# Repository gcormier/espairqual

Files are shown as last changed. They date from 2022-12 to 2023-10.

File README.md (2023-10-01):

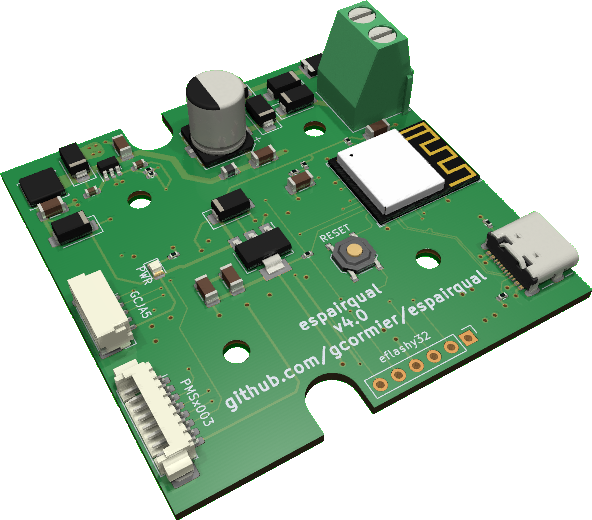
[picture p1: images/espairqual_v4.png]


# espairqual
espairqual is an ESP32 based [esphome](https://esphome.io/) interface for [PMSx003](https://esphome.io/components/sensor/pmsx003.html) and [Panasonic NA-GCJA5](https://na.industrial.panasonic.com/products/sensors/air-quality-gas-flow-sensors/lineup/laser-type-pm-sensor/series/123557/model/123559) particulate matter (PM) sensors.



It offers a plug and play solution to integrate air quality monitoring with home assistant. It provides 5V to the sensor and 3.3V to the internal electronics.

It can be powered by USC-C, or, by a wider range of input voltages on the screw terminals. It was designed for 24VAC, but will likely work with a slightly broader range
of both AC and DC input voltages. The absolute maximum voltage for the switching regulator is 40VDC, which means up to around 28VAC. The minimum DC is approximately 9VDC.

The PCB will fit inside a [Hammond 1593KBK](https://www.hammfg.com/part/1593KBK) case. You can either cut (CNC) or 3D-print the faceplates. I have superglue'd some magnets inside the case so it can stick to my ductwork, although this attenuates the WiFi signal *alot*.

## Programming
The USB-C port can be used to program. The first time, the reset button must be held. After this, all subsequent programming does not require access to the button.

There is also a header for the typical serial flashing with GPIO0(9) and EN exposed. It follows my [eflashy32](https://github.com/gcormier/eflashy32) pinout.

## Panasonic SN-GCJA5
I contributed native support for the SN-GCJA5 [to esphome](https://esphome.io/components/sensor/gcja5.html). While the PMS5003 is a good sensor, I did receive one dead-on-arrival from Aliexpress. The Panasonic sensor is cheaper, smaller, available from tier-1 distributors (eg. [Digikey](https://www.digikey.ca/en/products/detail/panasonic-electronic-components/SN-GCJA5/10443899)) and has a 5+ year life expectancy. It has internal compensation for the fan, photo diode and laser diode.

The connector is JST-GH (1.25mm) series.

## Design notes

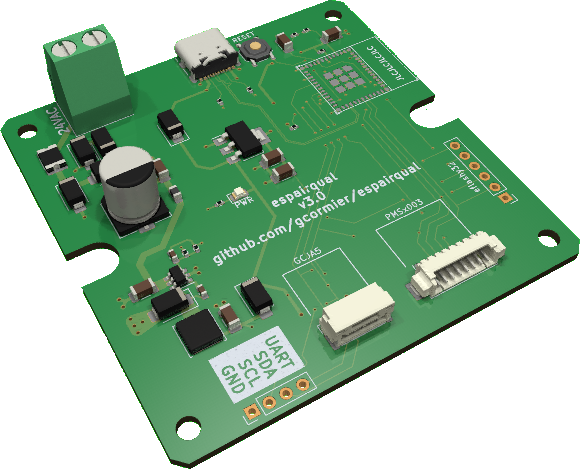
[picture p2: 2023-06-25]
images/espairqual_v3.png

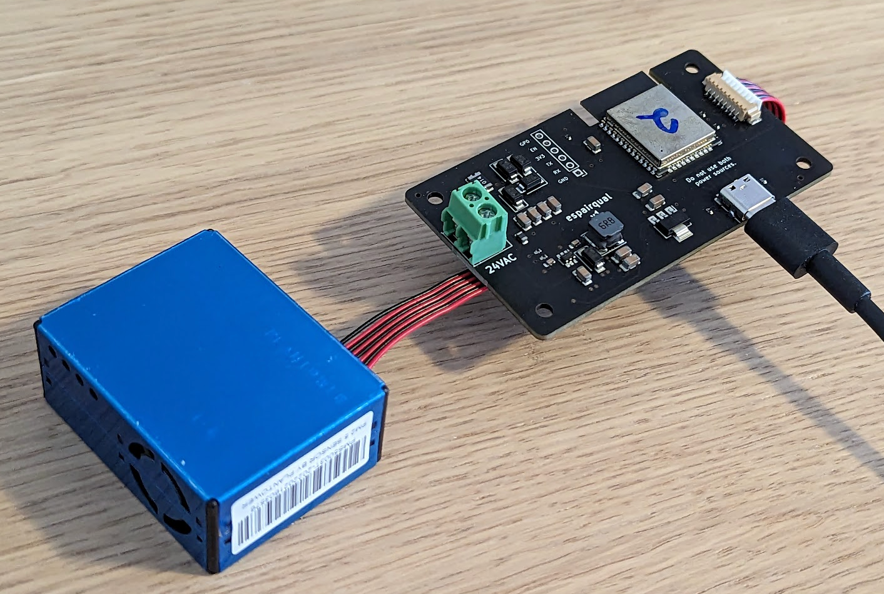
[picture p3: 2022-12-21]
images/espairqual.png

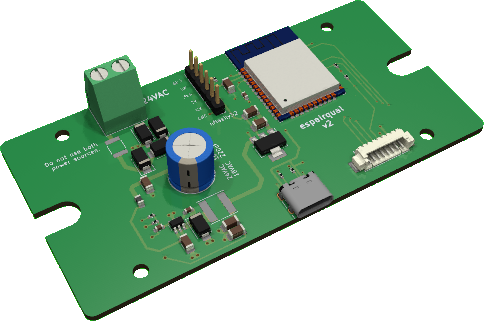
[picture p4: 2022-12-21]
images/espairqual-3D.png

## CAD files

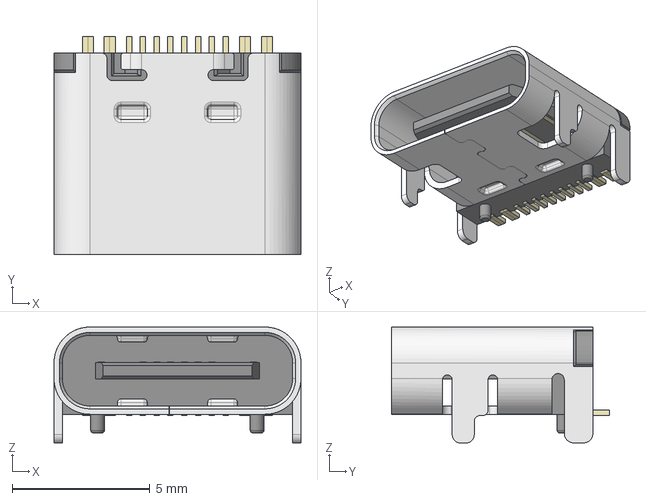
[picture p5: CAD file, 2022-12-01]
pcb/HRO_TYPE-C-31-M-12.step
8.95 x 7.90 x 4.20 mm

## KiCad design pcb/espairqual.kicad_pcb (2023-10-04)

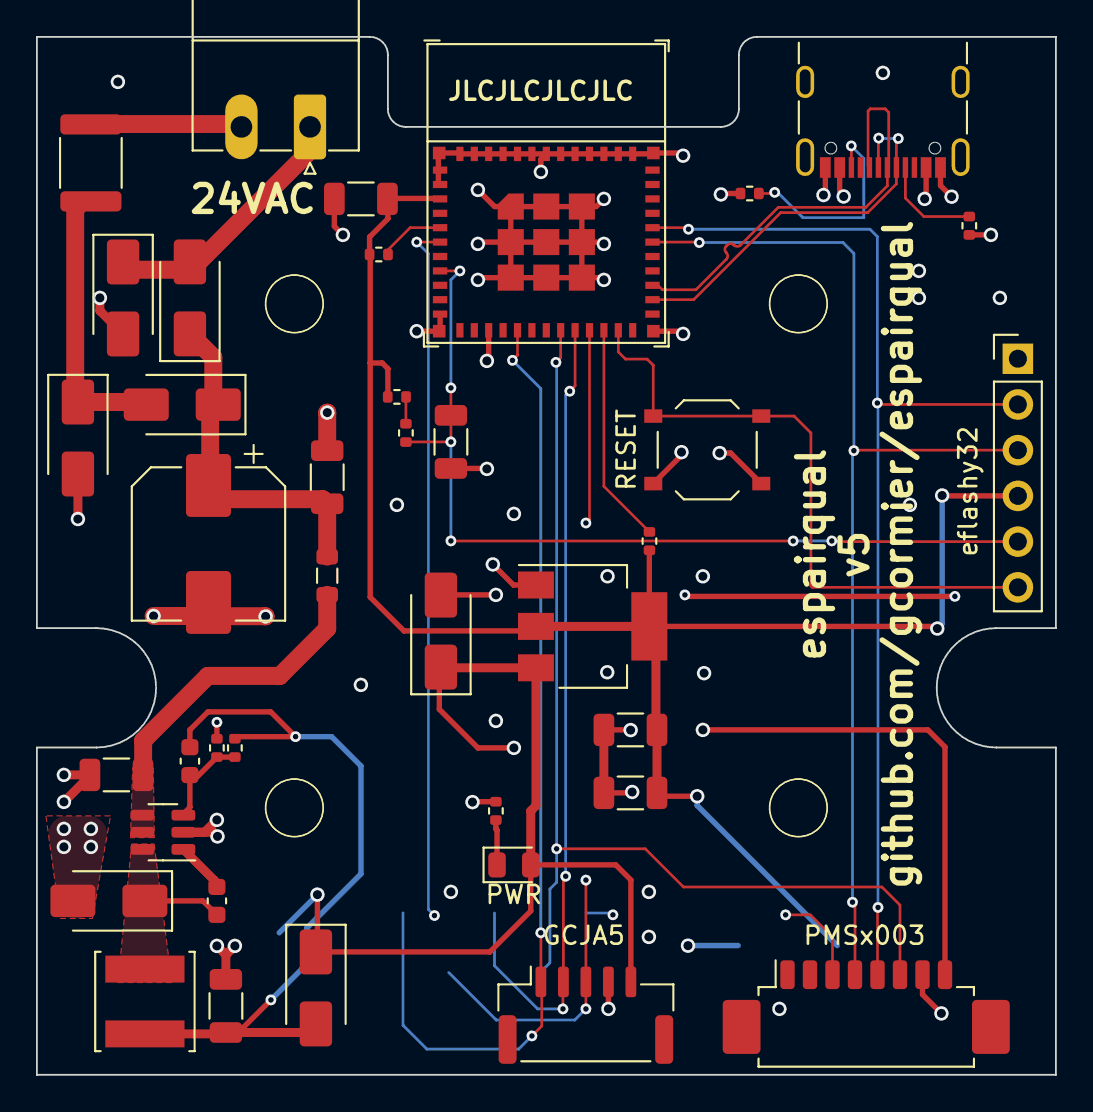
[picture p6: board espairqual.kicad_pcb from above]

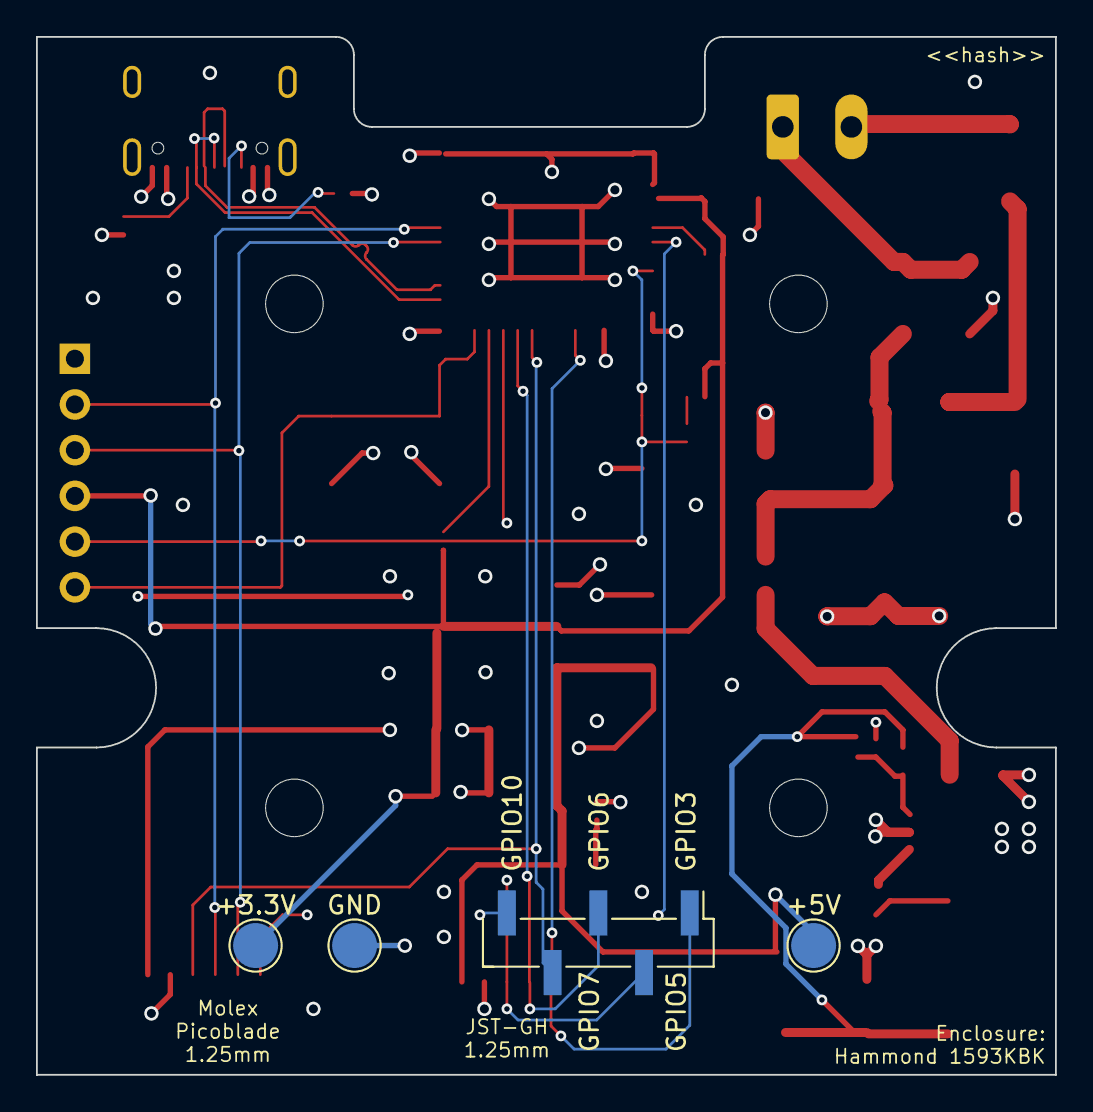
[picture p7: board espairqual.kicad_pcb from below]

Board: 4 copper layers, 56.6 x 57.7 mm, 47 parts (4 on the bottom side), 30 nets.

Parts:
C1, C6, C7, C8, C9, C11, C12: 10uF 50V; C_1206_3216Metric
C4: 0.1u 25v; C_0603_1608Metric
C5: 15nF; C_0603_1608Metric
C10: 100uF 50V; CP_Elec_8x10
D1, D2, D3, D4, D5, D6, D7: SS210; D_SMA
D8: PWR; LED_0805_2012Metric
F1: 140mA hold / 340mA trip mSMD014; Fuse_1812_4532Metric
FB1: 600@100MHz; L_0805_2012Metric
H1, H2, H3, H4: MountingHole; MountingHole_3.2mm_M3
J1: 24VAC; PhoenixContact_MC_1,5_2-G-3.81_1x02_P3.81mm_Horizontal
J2: PMSX003; Molex_PicoBlade_53261-0871_1x08-1MP_P1.25mm_Horizontal
J3: eflashy32; PinHeader_1x06_P2.54mm_Vertical
J4: USBC; USB_C_Receptacle_GCT_USB4105-xx-A_16P_TopMnt_Horizontal
J5: GCJA5; JST_GH_SM05B-GHS-TB_1x05-1MP_P1.25mm_Horizontal
J7: AUX; PinHeader_1x05_P2.54mm_Vertical_SMD_Pin1Left
L1: 6.8uH; L_Sunlord_SWPA5012S
R1, R3, R4, R5, R10, R11: 5k1; R_0402_1005Metric
R2, R6: 680; R_0402_1005Metric
R12: 3k9; R_0402_1005Metric
SW1: RESET; SW_Push_1P1T_XKB_TS-1187A
TP1: +5V; TestPoint_Pad_D2.5mm
TP2: GND; TestPoint_Pad_D2.5mm
TP3: +3.3V; TestPoint_Pad_D2.5mm
U1: BD9G101G; SOT-23-6
U3: AMS1117-3.3; SOT-223-3_TabPin2
U4: ESP32-C3-MINI-1

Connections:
+3V3: C8.1, C9.1, C11.2, J3.4, R3.1, R4.1, R5.1, TP3.1, U3.2 (VO), U4.3 (3V3)
+5V: D6.1 (K), D7.1 (K), D8.2 (A), J2.8, J5.5, TP1.1, U3.3 (VI)
/EN: C12.2, J3.5, R1.2, U4.8 (EN/CHIP_PU)
/FB: C4.2, R2.2, R12.1, U1.3 (FB)
/GPIO0: J3.6, SW1.1 (A), U4.23 (GPIO9)
/GPIO3: J2.3, J7.5, U4.6 (GPIO3/ADC1_CH3)
/GPIO5: J2.6, J7.4, U4.19 (GPIO5/ADC2_CH0)
/GPIO6: J5.2, J7.3, U4.20 (GPIO6)
/GPIO7: J5.3, J7.2, U4.21 (GPIO7)
/GPIO10: J5.1, J7.1, U4.16 (GPIO10)
/LX: C5.2, D1.1 (K), L1.1, U1.6 (LX)
/PMS_RXD: J2.5, J3.2, U4.31 (GPIO21/U0TXD)
/PMS_TXD: J2.4, J3.3, U4.30 (GPIO20/U0RXD)
/PWR5V: D6.2 (A), J4.A4 (VBUS), J4.A9 (VBUS), J4.B4 (VBUS), J4.B9 (VBUS)
/Vrec: C6.1, C10.1, D3.1 (K), D5.1 (K), FB1.2
D+: J4.A6 (D+), J4.B6 (D+), U4.27 (GPIO19/USB_D+)
D-: J4.A7 (D-), J4.B7 (D-), U4.26 (GPIO18/USB_D-)
GND: C1.2, C6.2, C7.2, C8.2, C9.2, C10.2, C11.1, C12.1, D1.2 (A), D2.2 (A), D4.2 (A), J2.7, J3.1, J4.A1 (GND), J4.A12 (GND), J4.B1 (GND), J4.B12 (GND), J5.4, R2.1, R6.2, R10.2, R11.2, SW1.2 (B), TP2.1, U1.2 (GND), U3.1 (GND), U4.1 (GND), U4.2 (GND), U4.11 (GND), U4.14 (GND), U4.36 (GND), U4.37 (GND), U4.38 (GND), U4.39 (GND), U4.40 (GND), U4.41 (GND), U4.42 (GND), U4.43 (GND), U4.44 (GND), U4.45 (GND), U4.46 (GND), U4.47 (GND), U4.48 (GND), U4.49 (GND), U4.50 (GND), U4.51 (GND), U4.52 (GND), U4.53 (GND)
unnamed: D2.1 (K), D3.2 (A), F1.2
unnamed: D4.1 (K), D5.2 (A), J1.1
unnamed: C4.1, C7.1, D7.2 (A), L1.2, R12.2
unnamed: D8.1 (K), R6.1
unnamed: F1.1, J1.2
unnamed: J4.A5 (CC1), R10.1
unnamed: J4.B5 (CC2), R11.1
unnamed: R1.1, R3.2
unnamed: C5.1, U1.1 (BST)
unnamed: C1.1, FB1.1, U1.4 (EN), U1.5 (VIN)
unnamed: R4.2, U4.5 (GPIO2/ADC1_CH2)
unnamed: R5.2, U4.22 (GPIO8)

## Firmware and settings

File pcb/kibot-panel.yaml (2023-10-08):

kibot:
  version: 1

filters:
  - name: only_jlc_parts
    comment: 'Only parts with JLC (LCSC) code'
    type: generic
    include_only:
      - column: 'LCSC'
        regex: '^.+'

variants:
  - name: rotated
    comment: 'Just a place holder for the rotation filter'
    type: kibom
    variant: rotated
    pre_transform: _rot_footprint

outputs:
  - name: 'panel'
    type: panelize
    options:
      title: '+ (Panel)'
      units: mm
      configs:
        - layout:
            rows: 2
            cols: 2
            hspace: 0mm
            vspace: 4mm
          tabs:
            type: full
            cutout: 2mm
          cuts:
            type: vcuts
            layer: Edge.Cuts
          framing:
            type: railstb
            width: 10mm
            space: 3mm
            fillet: 1mm
            mintotalwidth: 70mm
            mintotalheight: 70mm
          tooling:
            type: 4hole
            hoffset: 5mm
            voffset: 2.5mm
            size: 2mm
          fiducials:
            type: 4fid
            hoffset: 15mm
            voffset: 3.85mm
            coppersize: 1mm
            opening: 2mm
          text:
            type: simple
            text: JLCJLCJLCJLC
            anchor: mt
            voffset: 2.5
            hjustify: center
            vjustify: center
          text2:
            type: simple
            text: Design created on {date}
            anchor: mb
            voffset: -2.5
            hjustify: center
            vjustify: center
          post:
            refillzones: true
            millradius: 1mm

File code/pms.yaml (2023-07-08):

# Sample espairqual config using the PlanTower PM3 sensor
esp32:
  board: esp32-c3-devkitm-1

esphome:
  name: plan-pm3
  on_boot:
    then:
      - output.turn_on: gpio3_output
      - output.turn_on: gpio5_output

wifi:
  ssid: !secret wifi_ssid
  password: !secret wifi_password

  # Enable fallback hotspot (captive portal) in case wifi connection fails
  ap:
    ssid: "espairqualFallback"
    password: "espairqual"


# Enable logging
# do not use serial logging
logger:
  level: VERBOSE
  baud_rate: 0

api:

ota:


uart:
  rx_pin: GPIO20
  tx_pin: GPIO21
  baud_rate: 9600

output:
  - platform: gpio
    pin: GPIO3
    id: gpio3_output

  - platform: gpio
    pin: GPIO5
    id: gpio5_output


sensor:
  - platform: pmsx003
    #type: PMSX003
    pm_1_0:
      name: "Particulate Matter <1.0µm Concentration"
    pm_10_0:
      name: "Particulate Matter <10.0µm Concentration"
    pm_2_5:
      name: "Particulate Matter <2.5µm Concentration"
    
    type: PMS5003T 
    temperature:
      name: "PMS Temperature"
    humidity:
      name: "PMS Humidity"
    update_interval: 60s

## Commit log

2022-12-01 esp32 time
    [espairqual.kicad_pcb, espairqual.kicad_sch]
2022-12-21 update workflow
    [espairqual.kicad_pcb, espairqual.kicad_sch]
2023-06-21 touchup before fab
    [espairqual.kicad_pcb, espairqual.kicad_sch]
2023-06-21 gerber filename
2023-07-08 update sample
2023-09-30 some tweaks
    [espairqual.kicad_pcb, espairqual.kicad_sch]
2023-10-04 final tweaks
    [espairqual.kicad_pcb, espairqual.kicad_sch]
